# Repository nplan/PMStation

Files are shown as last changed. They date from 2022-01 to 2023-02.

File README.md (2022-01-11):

# PMStation

An IoT device for monitoring particulate matter pollution in the air.

Features:
- ESP32 for brains and WiFi connectivity
- 3x PMS7003 sensor for increased accuracy and redundancy
- 2x HTU21D temperature & humidity sensor
- 3x expansion I2C headers for additional sensors
- Integrated 230V AC power supply
- Dual 40 mm fans for better measurement accuracy
- 3D printed wall mountable enclosure
- Arduino based software
- MQTT communication protocol

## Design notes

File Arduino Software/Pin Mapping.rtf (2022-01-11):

### BLINKY ###

modra LED: GPIO23

### TEMP / HUMD / PRESS —> I2C ###

temp/humd HTU21D #1 (bližje USB): I2C1 addr: 0x40
temp/humd HTU21D #2: I2C2 addr: 0x40

temp/pressure BMP280 (na breakoutu) I2C1 addr: 0x76

I2C1: SDA-> GPIO13 SCL-> GPIO14
I2C2: SDA-> GPIO26 SCL-> GPIO27

### AUX —> I2C ###

P101 I2C breakout: I2C2
P102 I2C breakout: I2C1

### PARTICLE —> UART ###

PM1 (bližje USB) RX-> GPIO19 TX-> GPIO21
PM2 (sredina RX-> GPIO05 TX-> GPIO18
PM3 RX-> GPIO16 TX-> GPIO17

### FAN —> PWM ###

FAN GPIO25

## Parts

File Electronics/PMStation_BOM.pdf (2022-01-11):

Comment | Description | Designator | Footprint | LibRef | Quantity
C3216X5R1C106K160A A | Multilayer Ceramic Capacitors 10uF ±10% 16V X5R SMD 1206 | C100, C102, C103, C104, C106 | FP-C3216-160-0_2-IPC_B | CMP-08246-003443-1 | | 5
CL10B104KB8NNNC | Multi-layer Ceramic Capacitor, -55 to 125 degC, 2-Pin SMD (0603), RoHS, Tape and Reel | C101, C105, C107, C108 | SAMS-C0603-2_M | CMP-2000-05332-1 | | 4
6 pin AWG30 direct solder connector | | CN1_ADP1, CN1_ADP2, CN1_ADP3, CN100, CN101, CN102 | 5 pin AWG30 direct solder connector | 6 pin AWG30 direct solder connector | | 6
B220A-13-F | DIODE SCHOTTKY 20V 2A SMA | D100 | FP-SMA-MFG | CMP-12790-000072-1 | | 1
0443001.DR. | FUSE, SMD, 1A, SLOW BLOW | F100 | FP-3403_0163_11-MFG | CMP-26293-000009-1 | | 1
62301021021 | SMT Vertical Socket Header WR-PHD, Pitch 1.27 mm, Dual Row, 10 pins | J1_ADP1, J1_ADP2, J1_ADP3 | 62301021021 | CMP-1502-01188-1 | | 3
691102710003 | Series 102 - 5.00 mm Horizontal Entry Modular with Pressure Clamp WR-TBL, 3 pin | J100 | 691102710003 | CMP-1502-03259-1 | | 1
USB4085-GF-A | CONN RCPT USB2.0 TYPEC 16POS | J101 | FP-USB4085-GF-A-MFG | CMP-196119-000001-1 | | 1
150080SS75000 | SMD mono-color Chip LED, WL-SMCW, Super Red | LED100 | 0805_A | CMP-1426-00010-1 | | 1
ESP32-WROOM-32 | RX TXRX MOD WIFI SURFACE MOUNT | MD100 | FP-ESP32-WROOM-32-MFG | CMP-194065-000008-1 | | 1
22-23-2031 | Male Header, Pitch 2.54 mm, 1 x 3 Position, Height 8.18 mm, Tail Length 3.56 mm, RoHS, Bulk | P100 | MOLX-22-23-2031_V | CMP-2000-05242-1 | | 1
Header 4 | Header, 4-Pin | P101 | HDR1X4 | Header 4 | | 1
Header 5 | Header, 5-Pin | P102 | HDR1X5 | Header 5 | | 1
Header 6 | Header, 6-Pin | P103 | HDR1X6 | Header 6 | | 1
BOOT | Header, 2-Pin | P104 | HDR1X2 | Header 2 | | 1
PMS70003 | PM1/2.5/10 airborne particle sensor. Silk tape mounting pattern only. Needs sepparate data connector. | PM100, PM101, PM102 | PMS7003 standing | PMS70003 | | 3
HLK-PM01 | HLK-PM01 compact AC-DC power supply 5V 600mA | PS100 | HLK-PMxx | HLK-PM01 | | 1
AO3400A | MOSFET N-CH 30V 5.7A SOT23 | Q100 | FP-SOT23-MFG | CMP-83955-000006-1 | | 1
MMBT3904 | General Purpose Transistor, NPN Silicon, 3-Pin SOT-23, Pb-Free, Tape and Reel | Q101, Q102 | ONSC-SOT-23-3-318-08_V | CMP-1048-00631-1 | | 2
10k | Chip Resistor, 10 KOhm, +/- 1%, 0.125 W, -55 to 155 degC, 0805 (2012 Metric), RoHS, Tape and Reel | R100, R103, R114, R116 | RESC2013X60X35NL10 T20 | CMP-1659-00013-4 | | 4
ERZE07A561 | VARISTOR 560V 2.5KA DISC 9MM | R101 | FP-ERZE07A561-MFG | CMP-05593-000004-1 | | 1
CRCW08055K10FKEA | RES Thick Film, 5.1kΩ, 1%, 0.125W, 100ppm/ °C, 0805 | R102, R104, R105, R106, R107, R108, R109, R110, R111, R112, R113, R115 | FP-CRCW0805-e3-MFG | CMP-2001-04024-2 | 12
RC0805FR-0710RL | Chip Resistor, 10 Ohm, +/- 1%, 0.125 W, -55 to 155 degC, 0805 (2012 Metric), RoHS, Tape and Reel | R117 | RESC2013X60X35ML10 T20 | CMP-2100-03670-1 | | 1
PTS645SM43SMTR92L FS | SWITCH TACTILE SPST-NO 0.05A 12V | SW100 | FP-PTS645SM43SMTR92L FS-MFG | CMP-2000-05160-2 | | 1
HTU21D | Digital Relative Humidity sensor with Temperature output | U100, U102 | FP-HTU21D-IPC_B | CMP-03340-000003-1 | | 2
LD1117S33TR | Fixed Low Drop Positive Voltage Regulator, 3.3V, 4-Pin SOT-223, Tape and Reel | U101 | SOT-223_L | CMP-0244-00310-1 | | 1
CP2102-GMR | Single-Chip USB to URAT Bridge, 3.3 V, -40 to 85 degC, 28-Pin QFN, RoHS, Tape and Reel | U103 | SLAB-QFN-28-3125x3125TP_M | CMP-2000-04924-1 | | 1

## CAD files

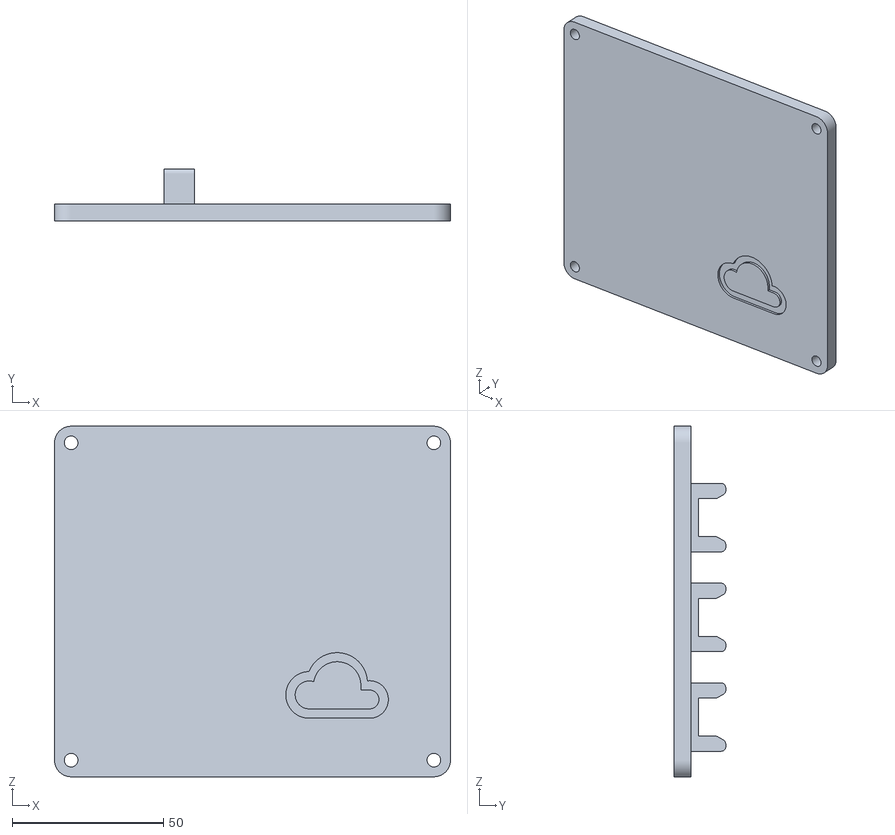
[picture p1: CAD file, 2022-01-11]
Case CAD/STL/case - case top.stl
131.0 x 17.1 x 116.0

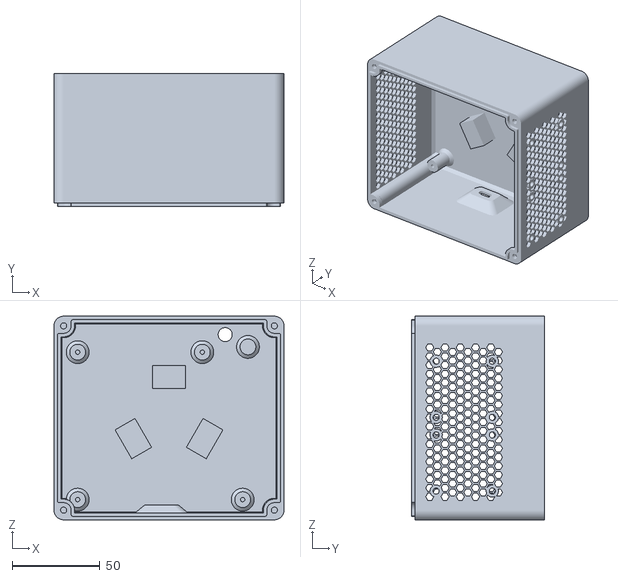
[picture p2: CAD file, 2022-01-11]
Case CAD/STL/case - case btm.stl
131.0 x 75.7 x 116.0

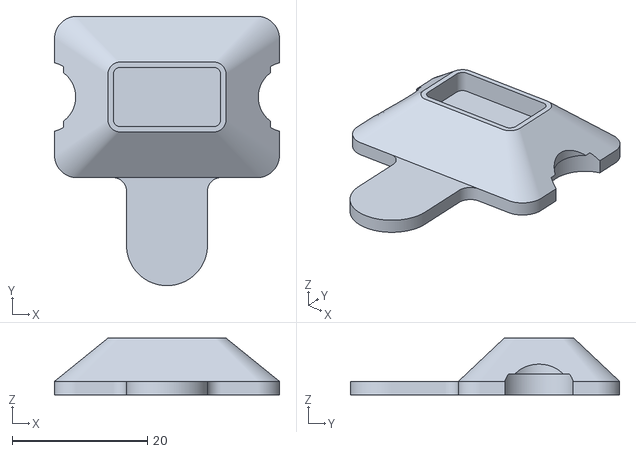
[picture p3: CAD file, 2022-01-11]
Case CAD/STL/case - usb cap.stl
33.3 x 39.9 x 8.40

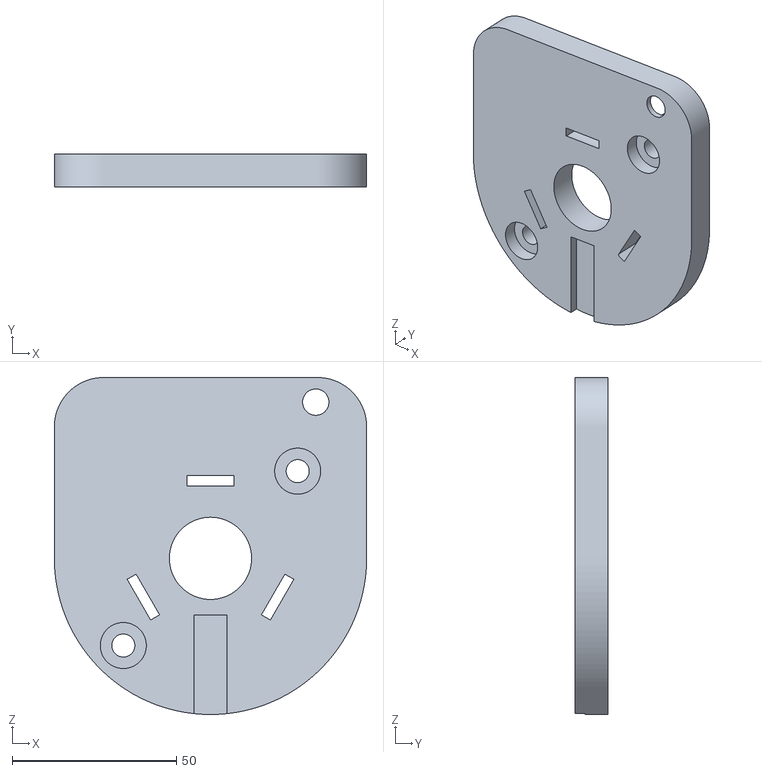
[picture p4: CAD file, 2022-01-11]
Case CAD/STL/case - mount.stl
95.0 x 10.0 x 102.5

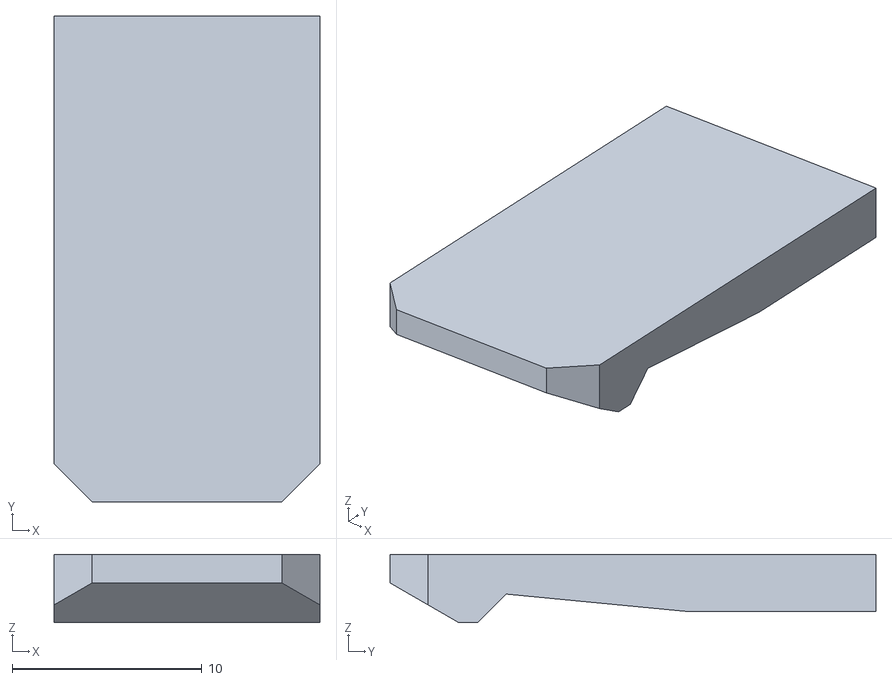
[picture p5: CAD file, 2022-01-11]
Case CAD/STL/case - clip.stl
14.0 x 25.6 x 3.59

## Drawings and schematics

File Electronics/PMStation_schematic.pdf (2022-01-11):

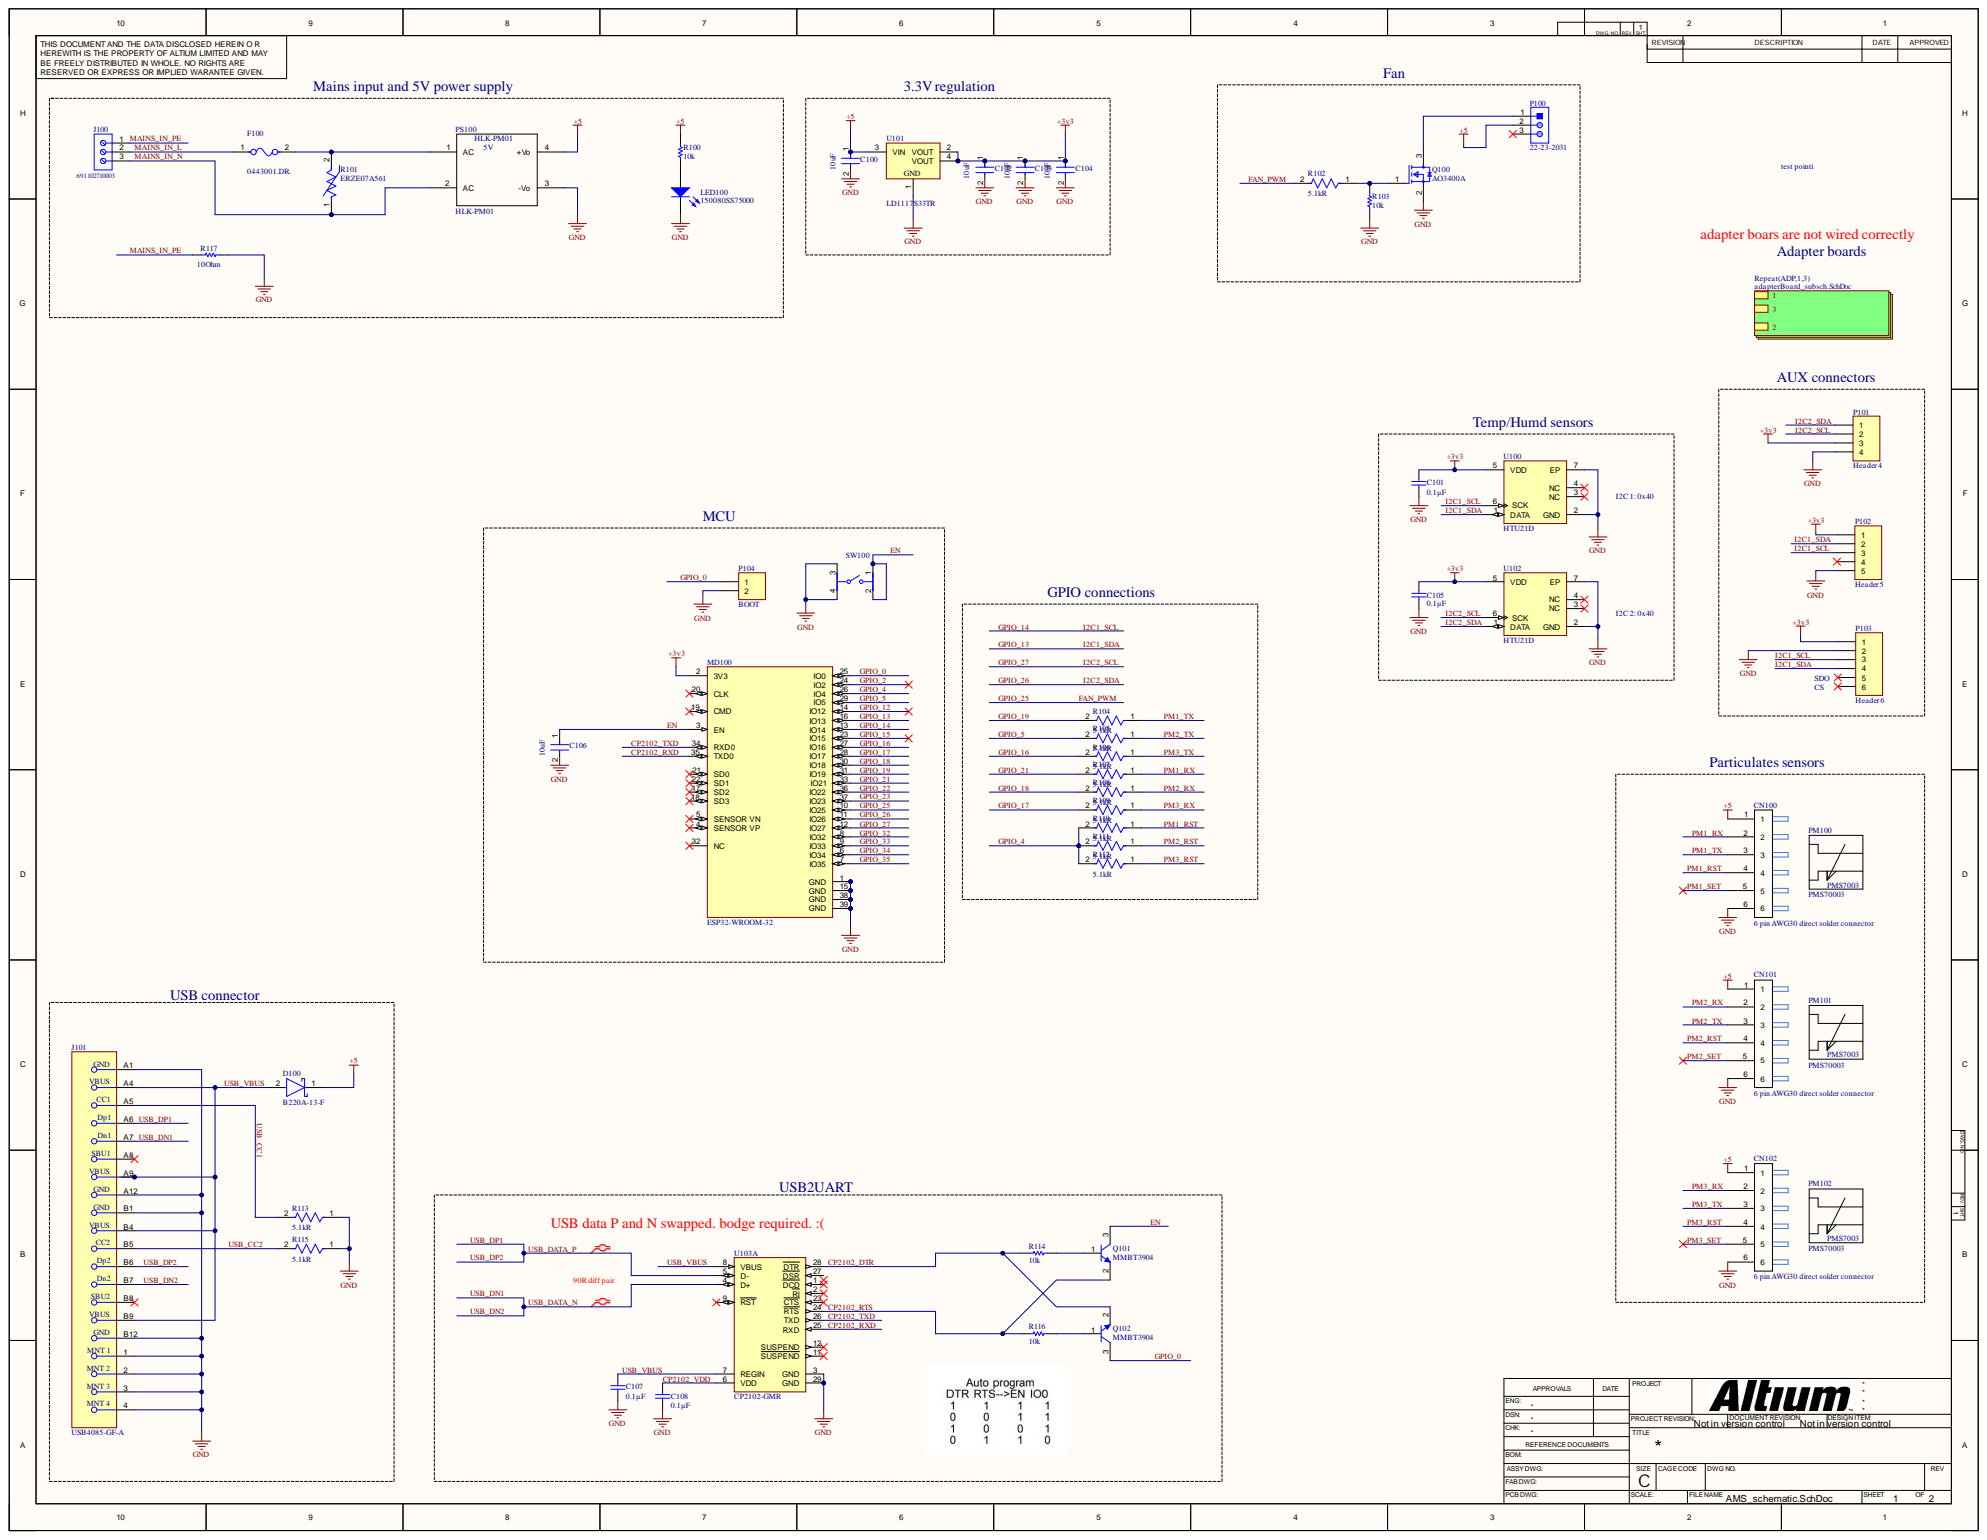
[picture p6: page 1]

DWG. NO. | REV. | SHT. 1

THIS DOCUMENTAND THE DATA DISCLOSED HEREIN OR HEREWITH IS THE PROPERTY OF ALTIUM LIMITED AND MAY BE FREELY DISTRIBUTED IN WHOLE. NO RIGHTS ARE RESERVED OR EXPRESS OR IMPLIED WARANTEE GIVEN. | Mains input and 5V power supply 3.3V regulation P100 | REVISION | DESCRIPTION | DATE | APPROVED

adapter boars are not wired correctly

6 pin AWG30 direct solder connector

REV. SHT. DWG. NO.

USB data P and N swapped. bodge required. :(

DSN: * | PROJECT REVISION: Not in version control | DOCUMENT REVISION: Not in version control | DESIGN ITEM:
CHK: * | TITLE *

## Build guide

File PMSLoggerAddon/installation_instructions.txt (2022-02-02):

1. Copy folder PMSLoggerAddon to /addons on Home Assistant OS filesystem
2. In homeasistant frontend go to Configuration > Add-ons and click ADD-ON-STORE in bottom right
3. Click menu in top right and select Check for updates
4. PMSLogger should apear in section Local add-ons. Click it.
5. Click install and wait a few minutes
6. Go to Configuration tab and fill in MQTT parameters. Click SAVE.
7. Back on Info tab click START.
8. Check Log tab to see if it started sucessfuly
9. On Info tab turn on Start on boot and Watchdog options
10. All done!

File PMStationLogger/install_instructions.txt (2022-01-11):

How to install as a service started at boot using systemd:

1. Place at /home/<user>/pms_logger.py

2. Run sudo chmod +x /home/<user>/pms_logger.py

3. Create file /lib/systemd/system/pms_logger.service with contents:

        [Unit]
        Description=PMS Logger
        After=multi-user.target

        [Service]
        Type=idle
        User=homeassistant
        ExecStart=python3 /home/<user>//pms_logger.py
        Restart=always
        RestartSec=30

        [Install]
        WantedBy=multi-user.target

4. Run sudo chmod 644 /lib/systemd/system/pms_logger.service

5. Run sudo systemctl daemon-reload

6. Run sudo systemctl enable pms_logger.service

7. Run sudo systemctl start pms_logger.service

8. Install complete! Logger will now start at boot and restart within 30 sec on any errors.

Check service status: sudo systemctl status pms_logger.service

View pms_logger service log: sudo journalctl -f -u pms_logger.service

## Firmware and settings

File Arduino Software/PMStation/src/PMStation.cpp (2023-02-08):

// board type: ESP32 Dev Module
// ESP32 arduino core == v2.0.0 (later versions do not work)
#include <Arduino.h>

#include <SoftwareSerial.h>
#include <HardwareSerial.h>
#include <WiFi.h>
#include <PubSubClient.h>
#include <PMS.h>
#include <Wire.h>
#include <SparkFunHTU21D.h>
#include <Adafruit_BMP280.h>
#include <RunningAverage.h>
#include <ArduinoJson.h>
#include <esp_task_wdt.h>
#include <WiFiManager.h>
#include <Preferences.h>

#include "config.h"

// Pins
#define LED_BUILTIN 23
#define FAN_PWM_PIN 25

// PM sensor UART pins
#define PMS1_RX 19
#define PMS1_TX 21
#define PMS2_RX 5
#define PMS2_TX 18
#define PMS3_RX 16
#define PMS3_TX 17

// I2C pins
#define I2C_1_SDA 13
#define I2C_1_SCL 14
#define I2C_2_SDA 26
#define I2C_2_SCL 27

// I2C adresses
#define htu21d_1_addr 0x40  // I2C 1
#define htu21d_2_addr 0x04  // I2C 2
#define bmp280_1_addr 0x76  // I2C 1

// Serial
#define PMS_BAUD 9600
SoftwareSerial pms1_ser(PMS1_RX, PMS1_TX);
SoftwareSerial pms2_ser(PMS2_RX, PMS2_TX);
SoftwareSerial pms3_ser(PMS3_RX, PMS3_TX);

WiFiClient wifi_client;
PubSubClient client(wifi_client);
bool wifi_available = false;
bool mqtt_available = false;

// WiFi manager
WiFiManager wm;
static WiFiManagerParameter mqtt_server_param("mqtt_server", "MQTT Server", "", 50);
static WiFiManagerParameter mqtt_port_param("mqtt_port", "MQTT Port", "", 6);
static WiFiManagerParameter mqtt_user_param("mqtt_user", "MQTT User", "", 50);
static WiFiManagerParameter mqtt_password_param("mqtt_password", "MQTT Password", "", 50);

Preferences prefs;
String mqtt_server = "";
int32_t mqtt_port = 0;
String mqtt_user = "";
String mqtt_password = "";

// PM sensors
PMS pms1(pms1_ser);
PMS::DATA pms1_data;

PMS pms2(pms2_ser);
PMS::DATA pms2_data;

PMS pms3(pms3_ser);
PMS::DATA pms3_data;

// I2C
TwoWire i2c_1(0);
TwoWire i2c_2(1);

// HTU21D sensors
HTU21D htu21d_1;
HTU21D htu21d_2;
const float temp_range_min = -100;
const float temp_range_max = 100;
const float humd_range_min = 0;
const float humd_range_max = 100;

// BMP280 sensors
Adafruit_BMP280 bmp280_1(&i2c_1);

// Data variables
const int nrSamples = 60;
RunningAverage pm10_1_avg(nrSamples);
RunningAverage pm10_2_avg(nrSamples);
RunningAverage pm10_3_avg(nrSamples);

RunningAverage pm25_1_avg(nrSamples);
RunningAverage pm25_2_avg(nrSamples);
RunningAverage pm25_3_avg(nrSamples);

RunningAverage pm100_1_avg(nrSamples);
RunningAverage pm100_2_avg(nrSamples);
RunningAverage pm100_3_avg(nrSamples);

RunningAverage temperature_1_avg(nrSamples);
RunningAverage temperature_2_avg(nrSamples);
RunningAverage temperature_x_avg(nrSamples);

RunningAverage humidity_1_avg(nrSamples);
RunningAverage humidity_2_avg(nrSamples);

RunningAverage pressure_avg(nrSamples);

float pm10_avg = 0;
float pm10_delta = 0;
float pm25_avg = 0;
float pm25_delta = 0;
float pm100_avg = 0;
float pm100_delta = 0;
float temperature_avg = 0;
float temperature_delta = 0;
float humidity_avg = 0;
float humidity_delta = 0;

// Char arrays
char pm10_avg_chr [20];
char pm25_avg_chr [20];
char pm100_avg_chr [20];
char temperature_avg_chr [20];
char humidity_avg_chr [20];
char pressure_avg_chr [20];

// Update sensor values interval
const unsigned long update_interval = 1 * 1000L;
unsigned long last_update_time = 0;
unsigned long last_publish_time = 0;

void save_prefs() {
  prefs.begin("mqtt");
  prefs.putString("mqtt_srv", mqtt_server);
  prefs.putUInt("mqtt_port", mqtt_port);
  prefs.putString("mqtt_user", mqtt_user);
  prefs.putString("mqtt_pass", mqtt_password);
  prefs.end();
}

void read_prefs() {
  prefs.begin("mqtt");
  mqtt_server = prefs.getString("mqtt_srv");
  mqtt_port = prefs.getUInt("mqtt_port");
  mqtt_user = prefs.getString("mqtt_user");
  mqtt_password = prefs.getString("mqtt_pass");
  prefs.end();
}

void param_callback() {
  mqtt_server = mqtt_server_param.getValue();
  mqtt_port = String(mqtt_port_param.getValue()).toInt();
  mqtt_user = mqtt_user_param.getValue();
  mqtt_password = mqtt_password_param.getValue();
  save_prefs();
}

void average_3_values(float val1, float val2, float val3, float &avg_out, float &max_err) {
  // exclude outlier and average remaining two
  float avg_all = (val1 + val2 + val3) / 3.0;
  float err1 = val1 - avg_all;
  float err2 = val2 - avg_all;
  float err3 = val3 - avg_all;

  if (err1 > err2 && err1 > err3) {
    avg_out = (val2 + val3) / 2.0;
    max_err = err1;
  }
  else if (err2 > err1 && err2 > err3) {
    avg_out = (val1 + val3) / 2.0;
    max_err = err2;
  }
  else {
    avg_out = (val1 + val2) / 2.0;
    max_err = err3;
  }
}

void average_2_values(float val1, float val2, float &avg_out, float &delta) {
  avg_out = (val1 + val2) / 2.0;
  delta = val1 - val2;
}


void print_all_data() {
  Serial.println("######## DATA ########"); Serial.println();
  Serial.println("[PM 1.0 (ug/m3)]");
  Serial.print("All sensors:"); Serial.print("\t");
  Serial.print(pm10_1_avg.getFastAverage(), 0); Serial.print("\t");
  Serial.print(pm10_2_avg.getFastAverage(), 0); Serial.print("\t");
  Serial.println(pm10_3_avg.getFastAverage(), 0);
  Serial.print("Average:"); Serial.print("\t");
  Serial.println(pm10_avg, 1);
  Serial.print("Delta:"); Serial.print("\t");
  Serial.println(pm10_delta, 1); Serial.println();

  Serial.println("[PM 2.5 (ug/m3)]");
  Serial.print("All sensors:"); Serial.print("\t");
  Serial.print(pm25_1_avg.getFastAverage(), 0); Serial.print("\t");
  Serial.print(pm25_2_avg.getFastAverage(), 0); Serial.print("\t");
  Serial.println(pm25_3_avg.getFastAverage(), 0);
  Serial.print("Average:"); Serial.print("\t");
  Serial.println(pm25_avg, 1);
  Serial.print("Delta:"); Serial.print("\t");
  Serial.println(pm25_delta, 1); Serial.println();

  Serial.println("[PM 10.0 (ug/m3)]");
  Serial.print("All sensors:"); Serial.print("\t");
  Serial.print(pm100_1_avg.getFastAverage(), 0); Serial.print("\t");
  Serial.print(pm100_2_avg.getFastAverage(), 0); Serial.print("\t");
  Serial.println(pm100_3_avg.getFastAverage(), 0);
  Serial.print("Average:"); Serial.print("\t");
  Serial.println(pm100_avg, 1);
  Serial.print("Delta:"); Serial.print("\t");
  Serial.println(pm100_delta, 1); Serial.println();

  Serial.println("[Temperature (*C)]");
  Serial.print("All sensors:"); Serial.print("\t");
  Serial.print(temperature_1_avg.getFastAverage(), 1); Serial.print("\t");
  Serial.println(temperature_2_avg.getFastAverage(), 1);
  Serial.print("Average: "); Serial.print("\t");
  Serial.println(temperature_avg, 1);
  Serial.print("Delta:"); Serial.print("\t");
  Serial.println(temperature_delta, 1); Serial.println();

  Serial.println("[Humidity (%)]");
  Serial.print("All sensors:"); Serial.print("\t");
  Serial.print(humidity_1_avg.getFastAverage(), 1); Serial.print("\t");
  Serial.println(humidity_2_avg.getFastAverage(), 1);
  Serial.print("Average:"); Serial.print("\t");
  Serial.println(humidity_avg, 1);
  Serial.print("Delta:"); Serial.print("\t");
  Serial.println(humidity_delta, 1); Serial.println();

  Serial.println("[Pressure (hPa)]");
  Serial.println(pressure_avg.getFastAverage(), 0);
  Serial.println();
}

void wifi_handler_loop() {
  static uint8_t ctrl = 0;
  static uint32_t reconnect_time = 0;
  static const uint32_t connect_timeout = 20000;
  switch (ctrl) {
    case 0: // check wifi status
      if (WiFi.status() != WL_CONNECTED) {
        Serial.println("Reconnecting WiFi...");
        wifi_available = false;
        WiFi.disconnect(true);
        WiFi.begin();
        reconnect_time = millis();
        ctrl = 1;
      } else {
        wifi_available = true;
      }
      break;
    case 1: // wait for connection or timoeut
      if (WiFi.status() == WL_CONNECTED) {
        wifi_available = true;
        Serial.println("WiFi connected.");
        Serial.print("IP address: ");
        Serial.println(WiFi.localIP());
        ctrl = 0;
      }
      else if (millis() - reconnect_time > connect_timeout) {
        ctrl = 0;
      }
      break;
  }
}

void mqtt_handler_loop() {
  static uint8_t ctrl = 0;
  static uint32_t reconnect_time = 20000;
  static const uint32_t connect_timeout = 20000;
  switch (ctrl) {
    case 0: // check wifi status
      if (wifi_available && !client.connected() && millis() - reconnect_time > connect_timeout) {
        Serial.println("Reconnecting MQTT...");
        mqtt_available = false;
        if (mqtt_user.length() == 0 && mqtt_password.length() == 0) {
          client.connect(client_id);
        } else {
          client.connect(client_id, mqtt_user.c_str(), mqtt_password.c_str());
        }
        reconnect_time = millis();
        ctrl = 1;
      }
      break;
    case 1: // wait for connection or timoeut
      if (client.connected()) {
        mqtt_available = true;
        Serial.println("MQTT connected.");
        ctrl = 0;
      }
      else if (millis() - reconnect_time > connect_timeout) {
        Serial.print("MQTT connection failed, rc=");
        Serial.println(client.state());
        ctrl = 0;
      }
      break;
  }
}

void setup() {
  esp_task_wdt_init(120, true);
  esp_task_wdt_add(NULL);
  
  pinMode(LED_BUILTIN, OUTPUT);
  pinMode(FAN_PWM_PIN, OUTPUT);
  digitalWrite(LED_BUILTIN, HIGH);
  delay(500);
  digitalWrite(LED_BUILTIN, LOW);
  digitalWrite(FAN_PWM_PIN, HIGH);

  read_prefs();
  
  Serial.begin(115200);
  Serial.println("###### PMStation Active ######");
  Serial.println();
  
  pms1_ser.begin(PMS_BAUD);
  pms2_ser.begin(PMS_BAUD);
  pms3_ser.begin(PMS_BAUD);

  i2c_1.setPins(I2C_1_SDA, I2C_1_SCL);
  i2c_2.setPins(I2C_2_SDA, I2C_2_SCL);

  htu21d_1.begin(i2c_1);
  htu21d_2.begin(i2c_2);

  bmp280_1.begin(bmp280_1_addr);
  /* Default settings from datasheet. */
  bmp280_1.setSampling(Adafruit_BMP280::MODE_NORMAL,     /* Operating Mode. */
                       Adafruit_BMP280::SAMPLING_X2,     /* Temp. oversampling */
                       Adafruit_BMP280::SAMPLING_X16,    /* Pressure oversampling */
                       Adafruit_BMP280::FILTER_X16,      /* Filtering. */
                       Adafruit_BMP280::STANDBY_MS_500); /* Standby time. */

  mqtt_server_param.setValue(mqtt_server.c_str(), 50);
  mqtt_port_param.setValue(String(mqtt_port).c_str(), 6);
  mqtt_user_param.setValue(mqtt_user.c_str(), 50);
  mqtt_password_param.setValue(mqtt_password.c_str(), 50);
  wm.addParameter(&mqtt_server_param);
  wm.addParameter(&mqtt_port_param);
  wm.addParameter(&mqtt_user_param);
  wm.addParameter(&mqtt_password_param);
  wm.setTitle("PMS Station");
  wm.setSaveParamsCallback(param_callback);

  bool ret;
  ret = wm.autoConnect("PMS Station", "password");
  if (!ret) ESP.restart();
  
  wifi_client.setTimeout(1000);
  client.setSocketTimeout(2);
  client.setServer(mqtt_server.c_str(), mqtt_port);
  client.setBufferSize(1024);
}

void loop() {

  wifi_handler_loop();
  mqtt_handler_loop();
  client.loop();

  bool r1, r2, r3;
  r1 = pms1.read(pms1_data);
  r2 = pms2.read(pms2_data);
  r3 = pms3.read(pms3_data);
  
  if (millis() - last_update_time >= update_interval) {
    last_update_time = millis();
    esp_task_wdt_reset();

    // PM 1.0 um
    pm10_1_avg.addValue(pms1_data.PM_AE_UG_1_0);
    pm10_2_avg.addValue(pms2_data.PM_AE_UG_1_0);
    pm10_3_avg.addValue(pms3_data.PM_AE_UG_1_0);
    average_3_values(pm10_1_avg.getFastAverage(), pm10_2_avg.getFastAverage(), pm10_3_avg.getFastAverage(),
                      pm10_avg, pm10_delta);

    // PM 2.5 um
    pm25_1_avg.addValue(pms1_data.PM_AE_UG_2_5);
    pm25_2_avg.addValue(pms2_data.PM_AE_UG_2_5);
    pm25_3_avg.addValue(pms3_data.PM_AE_UG_2_5);
    average_3_values(pm25_1_avg.getFastAverage(), pm25_2_avg.getFastAverage(), pm25_3_avg.getFastAverage(),
                      pm25_avg, pm25_delta);

    // PM 10.0 um
    pm100_1_avg.addValue(pms1_data.PM_AE_UG_10_0);
    pm100_2_avg.addValue(pms2_data.PM_AE_UG_10_0);
    pm100_3_avg.addValue(pms3_data.PM_AE_UG_10_0);
    average_3_values(pm100_1_avg.getFastAverage(), pm100_2_avg.getFastAverage(), pm100_3_avg.getFastAverage(),
                      pm100_avg, pm100_delta);

    // Temperature
    float temp_1 = htu21d_1.readTemperature();
    float temp_2 = htu21d_2.readTemperature();
    if (temp_1 > temp_range_min && temp_1 < temp_range_max) {
      temperature_1_avg.addValue(temp_1);
    }
    if (temp_2 > temp_range_min && temp_2 < temp_range_max) {
      temperature_2_avg.addValue(temp_2);
    }
    average_2_values(temperature_1_avg.getFastAverage(), temperature_2_avg.getFastAverage(),
                      temperature_avg, temperature_delta);
    float temp_x = bmp280_1.readTemperature();
    temperature_x_avg.addValue(temp_x);
    
    // Humidity
    float humidity_1 = htu21d_1.readHumidity();
    float humidity_2 = htu21d_2.readHumidity();
    if (humidity_1 > humd_range_min && humidity_1 < humd_range_max) {
      humidity_1_avg.addValue(humidity_1);
    }
    if (humidity_2 > humd_range_min && humidity_2 < humd_range_max) {
      humidity_2_avg.addValue(humidity_2);
    }
    average_2_values(humidity_1_avg.getFastAverage(), humidity_2_avg.getFastAverage(),
                      humidity_avg, humidity_delta);

    // Pressure
    float pressure = bmp280_1.readPressure() / 100;
    pressure_avg.addValue(pressure);
  }

  if (millis() - last_publish_time >= publish_interval) {
    last_publish_time = millis();
    print_all_data();

    if (mqtt_available) {
      dtostrf(pm10_avg, 3, 0, pm10_avg_chr);
      dtostrf(pm25_avg, 3, 0, pm25_avg_chr);
      dtostrf(pm100_avg, 3, 0, pm100_avg_chr);
      client.publish(pm10_topic, pm10_avg_chr);
      client.publish(pm25_topic, pm25_avg_chr);
      client.publish(pm100_topic, pm100_avg_chr);
      
      dtostrf(temperature_avg, 5, 1, temperature_avg_chr);
      dtostrf(humidity_avg, 4, 1, humidity_avg_chr);
      dtostrf(pressure_avg.getFastAverage(), 6, 1, pressure_avg_chr);
      client.publish(temperature_topic, temperature_avg_chr);
      client.publish(humidity_topic, humidity_avg_chr);
      client.publish(pressure_topic, pressure_avg_chr);
  
      // Publish JSON
  
      StaticJsonDocument<1024> doc;
      doc["PM1.0_1"] = pm10_1_avg.getFastAverage();
      doc["PM1.0_2"] = pm10_2_avg.getFastAverage();
      doc["PM1.0_3"] = pm10_3_avg.getFastAverage();
      doc["PM1.0_avg"] = pm10_avg;
      doc["PM1.0_delta"] = pm10_delta;
      doc["PM2.5_1"] = pm25_1_avg.getFastAverage();
      doc["PM2.5_2"] = pm25_2_avg.getFastAverage();
      doc["PM2.5_3"] = pm25_3_avg.getFastAverage();
      doc["PM2.5_avg"] = pm25_avg;
      doc["PM2.5_delta"] = pm25_delta;
      doc["PM10.0_1"] = pm100_1_avg.getFastAverage();
      doc["PM10.0_2"] = pm100_2_avg.getFastAverage();
      doc["PM10.0_3"] = pm100_3_avg.getFastAverage();
      doc["PM10.0_avg"] = pm100_avg;
      doc["PM10.0_delta"] = pm100_delta;
      doc["temperature_1"] = temperature_1_avg.getFastAverage();
      doc["temperature_2"] = temperature_2_avg.getFastAverage();
      doc["temperature_x"] = temperature_x_avg.getFastAverage();
      doc["temperature_avg"] = temperature_avg;
      doc["temperature_delta"] = temperature_delta;
      doc["humidity_1"] = humidity_1_avg.getFastAverage();
      doc["humidity_2"] = humidity_2_avg.getFastAverage();
      doc["humidity_avg"] = humidity_avg;
      doc["humidity_delta"] = humidity_delta;
      doc["pressure"] = pressure_avg.getFastAverage();
  
      char buffer[1024];
      size_t n = serializeJson(doc, buffer);
      client.publish(raw_topic, (uint8_t*)buffer, n, false);
    }
    char buffer[40];
    sprintf(buffer, "MIN FREE HEAP: %d", ESP.getMinFreeHeap());
    Serial.println(buffer);
    if (ESP.getMinFreeHeap() < 20000UL) {
      ESP.restart();
    }
  }
  
}
